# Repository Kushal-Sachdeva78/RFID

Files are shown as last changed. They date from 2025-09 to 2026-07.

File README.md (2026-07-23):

# RFID Entry-Exit System for Vasant Valley School

A prototype of an RFID-based attendance, entry-exit, and laptop-borrowing system
built around the school's existing ID cards: ESP32 firmware with an RC522 reader
and TFT status display, a custom KiCad PCB, a FastAPI backend with a test suite,
and a web dashboard with optional Firebase mirroring.






## Motivation

At Vasant Valley School, attendance is marked manually by class teachers,
latecomers wait in a morning "late line" for manual strike marking, student
exits run on paper sign-out sheets, and borrowing a laptop needs a paper chit
signed across several flights of stairs. This project prototypes a replacement:
students and staff tap their existing ID cards, and the system records who
arrived, when, whether they were late, which way they are authorised to travel
home, and who is holding which laptop.

## What is in this repo

| Component | Path | What it does |
| --- | --- | --- |
| ESP32 firmware | `Main.ino` | Reads RC522 taps, keeps a real clock over NTP (with a simulated fallback), renders a status card, weekly grid, and entry/exit banner on the ILI9341 TFT, and posts each scan to the backend over Wi-Fi with retry and an offline buffer. Pin assignments match the fabricated board. |
| Backend service | `rfid_system/backend` | A FastAPI REST API covering health, roster, attendance events (entry/exit direction and second-resolution lateness), an office manual fallback, three-strike teacher notification, and laptop borrowing. Pydantic v2, timezone-aware, a swappable storage layer, role-scoped API keys, and a pytest suite. |
| Web dashboard | `rfid_system/frontend` | A static dashboard showing the roster, attendance events with direction, a gate exit-authorization banner, manual entry, and a laptop borrowing panel. Optional Firebase mirroring of manual scans. |
| PCB design | `RFID KICAD/` | Full KiCad schematic and board layout integrating the ESP32 DevKit V1, RFID reader, display, buzzer, power switch, and battery holder, with exported Gerbers in `RFID KICAD/RFID_PCB/`. |

## Features

- Attendance to the second against a real clock, with the 08:05 cutoff and bus
  riders exempt from lateness. A repeat tap does not double-mark attendance.
- Entry and exit logging on a single gate reader (a per-day toggle), with the
  guard-facing display showing whether a departing student may walk, go by car,
  or take the bus.
- An office manual fallback for a forgotten or lost card, flagged manual and
  attributed to the staff member.
- Three late days in a learning cycle notify the class teacher through a
  pluggable notifier (a file/stdout default, or SMTP from environment
  variables). No credentials are committed.
- Laptop borrowing with a full state machine: a student requests, a teacher
  approves or denies, a tech-lab helper issues a numbered unit and records the
  return, and the dashboard shows outstanding loans and how long each is held.

## Hardware

| Component | Purpose |
| --- | --- |
| ESP32 DevKit V1 | Wi-Fi microcontroller running the firmware |
| RC522 RFID module (SPI) | Scans ID cards |
| ILI9341 320x240 TFT | Shows the scan result, lateness, direction, and transport authorization |
| Buzzer | Audible scan feedback |
| Custom PCB | Integrates the components (KiCad sources and Gerbers in this repo) |

The firmware pin defines match the nets on the fabricated board (RC522 SS on
GPIO14 and RST on GPIO27; TFT CS on GPIO5, DC on GPIO21, RST on GPIO22; buzzer on
GPIO15; shared SPI on GPIO18/23/19). Verify with a continuity check before
flashing a unit.

## Getting started

To run the software on a laptop with no hardware, follow
[`rfid_system/GETTING_STARTED.md`](rfid_system/GETTING_STARTED.md): it covers the
backend and its tests, the dashboard, compiling the firmware with `arduino-cli`,
the laptop borrowing flow, and optional Firebase setup.

Continuous integration (`.github/workflows/ci.yml`) runs the backend tests and a
firmware compile for the ESP32 DevKit V1 on every push.

## Status

Implemented in this prototype: the firmware (real clock, Wi-Fi posting, offline
buffer, corrected pins); the backend (attendance with direction and lateness,
manual fallback, three-strike notification, laptop borrowing) with a pytest
suite; the dashboard; and the complete PCB design.

Not yet done: Firebase Auth so the optional Firestore mirror can be enabled,
on-device roster caching so the gate can identify all cards while offline, and
real per-user authentication in place of the prototype role keys.

## Developed by

**Kushal Sachdeva**, Vasant Valley School

More of my work: [github.com/Kushal-Sachdeva78](https://github.com/Kushal-Sachdeva78),
including [autonomous RoboCup soccer robots](https://github.com/Kushal-Sachdeva78/VVS-Ballers-RoboCup)
and [EnerJee](https://github.com/Kushal-Sachdeva78/EnerJee), a renewable energy
planning platform.

## License

This project is licensed under the MIT License. See [LICENSE](LICENSE) for details.

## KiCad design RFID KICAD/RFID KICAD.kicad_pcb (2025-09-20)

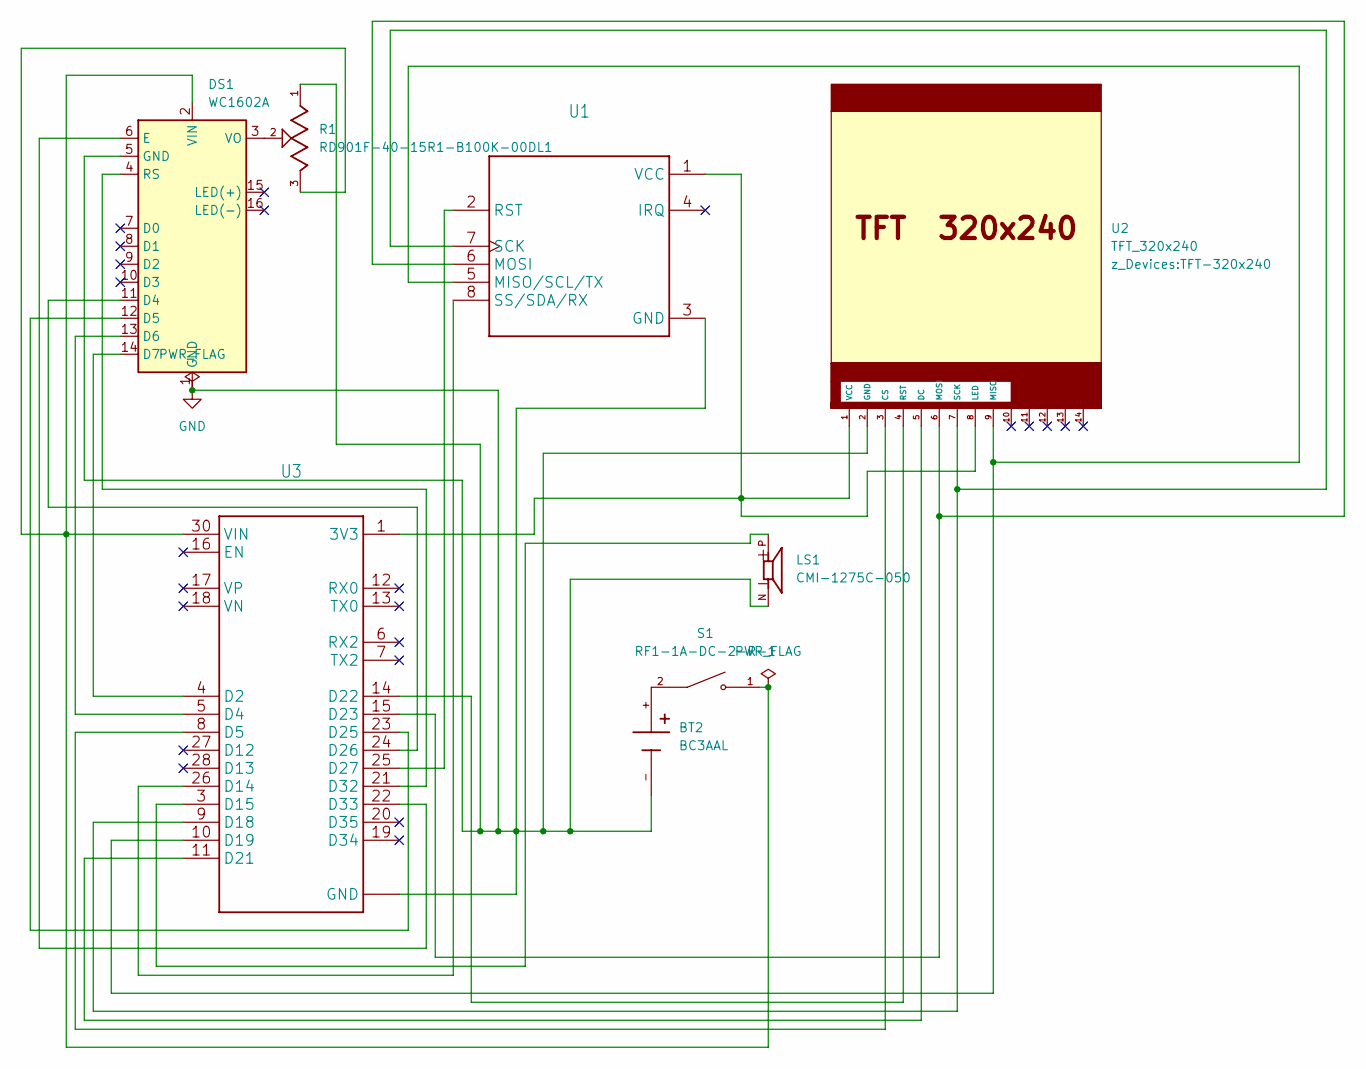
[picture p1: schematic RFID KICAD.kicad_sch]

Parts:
BT2: BC3AAL; BAT_BC3AAL; PARTREV J
DS1: WC1602A
LS1: CMI-1275C-050; CUI_CMI-1275C-050
R1: RD901F-40-15R1-B100K-00DL1; POT_RD901F-40-15R1-B100K-00DL1; PARTREV 10/5/23
S1: RF1-1A-DC-2-R-1; SW_RF1-1A-DC-2-R-1; PARTREV B
U1: MODULE_CEG006900
U2: TFT_320x240; TFT-320x240
U3: MODULE_ESP32_DEVKIT_V1

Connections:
GND: BT2.-, DS1.1 (GND), DS1.5 (GND), LS1.N, R1.1, U1.3 (GND), U2.2 (GND), U3.2 (GND), U3.29 (GND)
unnamed: BT2.+, S1.2
unnamed: DS1.11 (D4), U3.24 (D26)
unnamed: DS1.12 (D5), U3.23 (D25)
unnamed: DS1.13 (D6), U3.5 (D4)
unnamed: DS1.14 (D7), U3.4 (D2)
unnamed: DS1.6 (E), U3.22 (D33)
unnamed: DS1.4 (RS), U3.21 (D32)
unnamed: DS1.2 (VIN), R1.3, S1.1, U3.30 (VIN)
unnamed: DS1.3 (VO), R1.2
unnamed: U1.5 (MISO/SCL/TX), U2.9 (MISO), U3.10 (D19)
unnamed: U1.6 (MOSI), U2.6 (MOSI), U3.15 (D23)
unnamed: U1.2 (RST), U3.25 (D27)
unnamed: U1.7 (SCK), U2.7 (SCK), U3.9 (D18)
unnamed: U1.8 (SS/SDA/RX), U3.26 (D14)
unnamed: U1.1 (VCC), U2.1 (VCC), U2.8 (LED), U3.1 (3V3)
unnamed: U2.3 (CS), U3.8 (D5)
unnamed: U2.5 (DC), U3.11 (D21)
unnamed: U2.4 (RST), U3.14 (D22)
unnamed: LS1.P, U3.3 (D15)

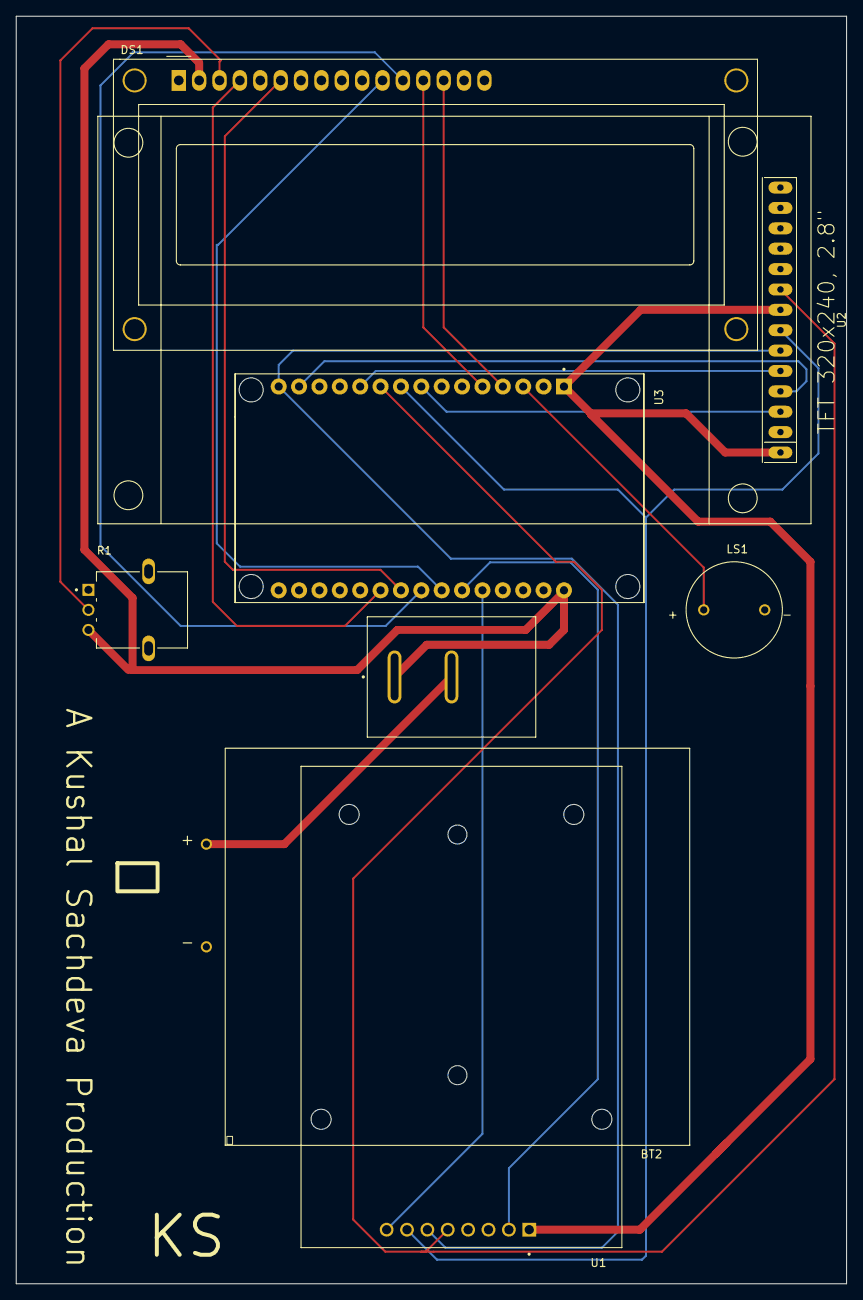
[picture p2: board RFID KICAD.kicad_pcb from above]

Board: 2 copper layers, 103.5 x 158.0 mm, 8 parts (0 on the bottom side), 20 nets.

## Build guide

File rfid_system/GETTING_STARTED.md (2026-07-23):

# Getting Started

Run the RFID system on a laptop with no hardware, then optionally compile the
firmware and wire up Firebase. Every step below runs with no credentials.

---

## 1. Backend

```bash
cd rfid_system/backend
python -m venv .venv
# macOS / Linux:
source .venv/bin/activate
# Windows (PowerShell):
.venv\Scripts\Activate.ps1

pip install -r requirements.txt -r requirements-dev.txt
uvicorn main:app --reload
```

The API listens on `http://127.0.0.1:8000`. Check it with:

```bash
curl http://127.0.0.1:8000/api/health
```

Run the tests:

```bash
pytest -q
```

### Configuration (all optional, via environment variables)

| Variable | Default | Purpose |
| --- | --- | --- |
| `RFID_TZ_OFFSET_MINUTES` | `330` | Local timezone offset. Default is India Standard Time (UTC+5:30, no daylight saving). |
| `RFID_LATE_HOUR` / `RFID_LATE_MINUTE` | `8` / `5` | Lateness cutoff (08:05). |
| `RFID_LEARNING_CYCLES` | one cycle, 08 Jul to 15 Oct 2026 | JSON array of `{name, start, end}` date ranges for strike tracking. |
| `RFID_STRIKE_THRESHOLD` | `3` | Late days in a cycle before the class teacher is notified. |
| `RFID_MAX_CONCURRENT_LOANS` | `1` | Active laptop loans a student may hold at once. |
| `RFID_SCAN_DEBOUNCE_SECONDS` | `60` | A repeat tap inside this window is a duplicate, not an exit. |
| `RFID_NOTIFIER` | `log` | Notifier backend: `log` (file plus stdout), `smtp`, or `none`. |
| `RFID_API_KEYS` | unset | JSON object of `{"key": "role"}` enabling role checks (see below). |

### Roles (prototype-grade)

By default there is no authentication, so the repo runs with no credentials.
When `RFID_API_KEYS` is set, privileged endpoints require an `X-API-Key` header
mapped to a role. This is a single shared key per role, not per-user login, and
is documented as a prototype, not production security. Example:

```bash
export RFID_API_KEYS='{"office-key":"office","teacher-key":"teacher","helper-key":"helper","admin-key":"admin"}'
```

Role requirements: manual attendance entry and roster writes need `office`,
`teacher`, or `admin`; laptop register or repair needs `helper` or `admin`; loan
approve or deny needs `teacher`; issue or return needs `helper`. The `admin` role
is allowed everywhere. Device scans and student borrow requests are open.

### Notifications (three-strike rule)

Three late days within a learning cycle notify the student's class teacher. The
class teacher is looked up in `data/class_teachers.json` by class section. The
default notifier writes to `data/notifications.log` and stdout, so no email
credentials are needed. To send email instead, set `RFID_NOTIFIER=smtp` and the
`SMTP_HOST`, `SMTP_PORT`, `SMTP_USER`, `SMTP_PASSWORD`, and `SMTP_FROM` variables.
No credentials are ever committed.

---

## 2. Dashboard

```bash
cd rfid_system/frontend
python -m http.server 5173
```

Browse to `http://localhost:5173`, enter the backend URL (`http://127.0.0.1:8000`)
in the Backend Connection card, and click Connect. The dashboard shows the roster,
attendance events with entry/exit direction, a gate preview with the exit
authorization banner, the manual entry form, and the laptop borrowing panel. If
the backend is stopped, manual scans are buffered locally.

---

## 3. Firmware (compile only)

The firmware target is the ESP32 DevKit V1. There is no hardware step here: a
clean compile is the gate.

```bash
arduino-cli core install esp32:esp32
arduino-cli lib install "MFRC522" "Adafruit GFX Library" "Adafruit ILI9341"
bash scripts/compile_firmware.sh
```

`scripts/compile_firmware.sh` stages `Main.ino` into `build/Main/` so the tracked
file is never moved. To run against hardware, copy `arduino_secrets.example.h` to
`arduino_secrets.h` (gitignored) and set your Wi-Fi and backend URL. With no
secrets file, or an empty SSID, the firmware runs fully offline.

---

## 4. Laptop borrowing flow

You can drive the whole flow from the dashboard Laptop Borrowing panel, or with
curl (with `RFID_API_KEYS` unset, no keys are needed):

```bash
B=http://127.0.0.1:8000
curl -s -X POST $B/api/laptops -H "Content-Type: application/json" -d '{"asset_code":"LT-042"}'
LOAN=$(curl -s -X POST $B/api/loans/request -H "Content-Type: application/json" -d '{"student_uid":"04 11 22 33"}' | python -c "import sys,json;print(json.load(sys.stdin)['id'])")
curl -s -X POST $B/api/loans/$LOAN/approve
curl -s -X POST $B/api/loans/$LOAN/issue -H "Content-Type: application/json" -d '{"asset_code":"LT-042"}'
curl -s $B/api/loans/outstanding
curl -s -X POST $B/api/loans/$LOAN/return
```

---

## 5. Firebase (optional)

Firestore mirroring of manual scans is optional. Copy the example config and fill
in your project:

```bash
cp rfid_system/frontend/firebase.config.example.js rfid_system/frontend/firebase.config.js
```

`firebase.config.js` is gitignored. When it is absent, the dashboard runs normally
with mirroring disabled. A Firebase web apiKey is not a secret (it ships to every
browser); the real protection is the Firestore rules below.

### Firestore security rules

These restrict access to authenticated clients. Wiring up Firebase Auth in the
dashboard is out of scope for this prototype, so mirroring is off until that is
added.

```text
rules_version = '2';
service cloud.firestore {
  match /databases/{database}/documents {
    match /manual_scans/{document=**} {
      allow read, write: if request.auth != null;
    }
  }
}
```

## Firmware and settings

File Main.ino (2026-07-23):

#include <WiFi.h>
#include <HTTPClient.h>
#include <SPI.h>
#include <MFRC522.h>
#include <Adafruit_GFX.h>
#include <Adafruit_ILI9341.h>
#include <ctype.h>
#include <string.h>
#include <time.h>

// -----------------------------------------------------------------------------
// Network and backend configuration.
// Real Wi-Fi credentials and the backend URL live in arduino_secrets.h, which
// is gitignored. Copy arduino_secrets.example.h to arduino_secrets.h and fill it
// in. When the header is absent (for example in CI, which only compiles), these
// placeholders keep the sketch building. With an empty SSID the firmware runs
// fully offline: it still reads cards and renders, and buffers scans to send
// later once a backend URL and network are configured.
// -----------------------------------------------------------------------------
#if __has_include("arduino_secrets.h")
#include "arduino_secrets.h"
#endif
#ifndef WIFI_SSID
#define WIFI_SSID ""
#endif
#ifndef WIFI_PASSWORD
#define WIFI_PASSWORD ""
#endif
#ifndef BACKEND_BASE_URL
#define BACKEND_BASE_URL "http://192.168.1.100:8000"
#endif
#ifndef READER_LOCATION
#define READER_LOCATION "main_gate"
#endif

// -----------------------------------------------------------------------------
// Hardware pin assignments.
// These match the nets on the fabricated KiCad board (ESP32 DevKit V1). The
// earlier values (SS 10, RST 9, TFT_RST 8, BUZZER 6) were leftover from a
// different board: they point at GPIO 6 to 11, which are bonded to the internal
// SPI flash on the WROOM-32 and are not broken out on the DevKit header. The
// shared SPI bus (SCK 18, MOSI 23, MISO 19) is the VSPI default and is wired to
// both the RC522 and the TFT. Verify with a continuity check before flashing.
// -----------------------------------------------------------------------------
#define RFID_SS    14   // RC522 SS   -> ESP32 D14
#define RFID_RST   27   // RC522 RST  -> ESP32 D27
#define TFT_CS      5   // ILI9341 CS  -> ESP32 D5
#define TFT_DC     21   // ILI9341 DC  -> ESP32 D21
#define TFT_RST    22   // ILI9341 RST -> ESP32 D22
#define BUZZER     15   // Buzzer      -> ESP32 D15

// -----------------------------------------------------------------------------
// RFID reader + TFT display objects
// -----------------------------------------------------------------------------
MFRC522 rfid(RFID_SS, RFID_RST);
Adafruit_ILI9341 tft(TFT_CS, TFT_DC, TFT_RST);

// -----------------------------------------------------------------------------
// Timings and attendance thresholds
// -----------------------------------------------------------------------------
const uint16_t DISPLAY_MS   = 5000;   // how long to show a scan before idling
const uint8_t  LATE_HOUR    = 8;
const uint8_t  LATE_MIN     = 5;
const uint8_t  START_HOUR   = 7;      // simulated start-of-day clock (fallback only)
const uint8_t  START_MINUTE = 45;

// -----------------------------------------------------------------------------
// Real clock (NTP) and networking constants.
// India Standard Time is UTC+5:30 with no daylight saving, so a fixed offset is
// exact all year. If NTP never syncs, the firmware falls back to the simulated
// clock above so the demo still works with no network.
// -----------------------------------------------------------------------------
const long     GMT_OFFSET_SEC       = 19800;  // +5:30
const int      DST_OFFSET_SEC       = 0;
const char*    NTP_SERVER_1         = "pool.ntp.org";
const char*    NTP_SERVER_2         = "time.nist.gov";
const char*    TZ_SUFFIX            = "+05:30"; // for ISO 8601 timestamps

const uint32_t WIFI_CONNECT_TIMEOUT_MS = 8000;  // bounded wait at startup
const uint32_t NET_MAINT_INTERVAL_MS   = 15000; // reconnect / resync / flush cadence
const uint8_t  HTTP_RETRIES            = 2;
const uint16_t HTTP_RETRY_DELAY_MS     = 200;
const uint16_t HTTP_TIMEOUT_MS         = 4000;

const int      OFFLINE_BUFFER_SIZE     = 32;   // scans held while offline
const int      PENDING_PAYLOAD_MAX     = 384;  // bytes per buffered scan

// -----------------------------------------------------------------------------
// Attendance data structures
// -----------------------------------------------------------------------------
enum AttendanceStatus : uint8_t {
  STATUS_ABSENT = 0,
  STATUS_PRESENT,
  STATUS_LATE
};

struct Person {
  const char* uid;          // hexadecimal UID string (space separated)
  const char* name;
  const char* role;         // Teacher / Student etc.
  const char* className;    // Homeroom or department label
  const char* transport;    // Mode of transport
  uint16_t    photoColor;   // Solid colour used for the mock photo tile
  AttendanceStatus week[5]; // Monday..Friday status history
  int lastDayKey;           // tracks the simulated day when this card was last marked
};

// Sample roster only. These names, UIDs, and sections are synthetic. On a real
// deployment the device would identify cards against the backend roster; this
// small on-device set is a fallback so the demo runs with no network.
Person roster[] = {
  {"04 11 22 33", "Sample Student", "Student", "Grade 10 - A", "Walk", ILI9341_BLUE,    {STATUS_ABSENT, STATUS_ABSENT, STATUS_ABSENT, STATUS_ABSENT, STATUS_ABSENT}, -1},
  {"04 44 55 66", "Sample Teacher", "Teacher", "Mathematics",  "Bus",  ILI9341_MAGENTA, {STATUS_ABSENT, STATUS_ABSENT, STATUS_ABSENT, STATUS_ABSENT, STATUS_ABSENT}, -1},
  {"04 77 88 99", "Demo Staff",     "Teacher", "Science",      "Car",  ILI9341_ORANGE,  {STATUS_ABSENT, STATUS_ABSENT, STATUS_ABSENT, STATUS_ABSENT, STATUS_ABSENT}, -1},
  {"04 AA BB CC", "Office Sample",  "Office",  "Admin",        "Car",  ILI9341_CYAN,    {STATUS_ABSENT, STATUS_ABSENT, STATUS_ABSENT, STATUS_ABSENT, STATUS_ABSENT}, -1}
};
const int ROSTER_COUNT = sizeof(roster) / sizeof(roster[0]);

// -----------------------------------------------------------------------------
// Global state used for simulated clock + display transitions
// -----------------------------------------------------------------------------
uint32_t bootMillis = 0;
uint32_t lastScreenUpdate = 0;
bool showingScan = false;
int initialisedDayKey = -1;

// Networking / clock state.
bool wifiConfigured = false;   // true when a non-empty SSID is compiled in
bool timeSynced = false;       // true once NTP has given us a real time
uint32_t lastNetMaintenance = 0;

// Guard-facing result of the most recent live scan, taken from the backend
// response headers (no JSON parsing needed on the device).
String lastDirection = "";
String lastAuthorization = "";

// Offline buffer: scans that could not be posted are kept here and flushed
// (oldest first) once the backend is reachable again.
struct PendingEvent {
  char payload[PENDING_PAYLOAD_MAX];
};
PendingEvent offlineBuffer[OFFLINE_BUFFER_SIZE];
int offlineCount = 0;
bool offlineDropped = false;   // set if the buffer overflowed (oldest dropped)

// -----------------------------------------------------------------------------
// Utility helpers
// -----------------------------------------------------------------------------
String uidToString(const MFRC522::Uid& uid) {
  String s;
  for (byte i = 0; i < uid.size; i++) {
    if (uid.uidByte[i] < 0x10) s += "0";
    s += String(uid.uidByte[i], HEX);
    if (i != uid.size - 1) s += " ";
  }
  s.toUpperCase();
  return s;
}

void softClockNow(int& hour, int& minute, int& dayKey) {
  uint32_t elapsedMinutes = (millis() - bootMillis) / 60000UL;
  uint32_t startMinutes   = START_HOUR * 60UL + START_MINUTE;
  uint32_t totalMinutes   = startMinutes + elapsedMinutes;

  hour   = (totalMinutes / 60UL) % 24;
  minute = totalMinutes % 60UL;
  dayKey = totalMinutes / (24UL * 60UL);
}

uint8_t currentWeekday(int dayKey) {
  // With a real clock, derive the weekday from the date. Monday maps to 0 and
  // Friday to 4; weekend days are clamped into the Friday column so the fixed
  // five column weekly grid never indexes out of bounds.
  if (timeSynced) {
    struct tm t;
    if (getLocalTime(&t, 0)) {
      uint8_t wd = (uint8_t)((t.tm_wday + 6) % 7); // Sun=0..Sat=6 -> Mon=0..Sun=6
      return wd > 4 ? 4 : wd;
    }
  }
  return dayKey % 5; // Monday (0) .. Friday (4) in the simulated fallback
}

bool arrivedLate(int hour, int minute, const char* transport) {
  if (transport != nullptr) {
    char first = transport[0];
    if (first == 'B' || first == 'b') {
      return false; // bus riders are exempt from lateness cutoffs
    }
  }
  if (hour > LATE_HOUR) return true;
  if (hour == LATE_HOUR && minute > LATE_MIN) return true;
  return false;
}

void toneOk() {
  digitalWrite(BUZZER, HIGH);
  delay(60);
  digitalWrite(BUZZER, LOW);
}

void toneError() {
  for (uint8_t i = 0; i < 2; ++i) {
    digitalWrite(BUZZER, HIGH);
    delay(40);
    digitalWrite(BUZZER, LOW);
    delay(40);
  }
}

String initialsOf(const char* name) {
  String initials;
  bool takeNext = true;
  for (const char* p = name; *p; ++p) {
    if (takeNext && isalpha(*p)) {
      initials += (char)toupper(*p);
      takeNext = false;
    }
    if (*p == ' ') {
      takeNext = true;
    }
    if (initials.length() == 2) break;
  }
  if (initials.length() == 0) {
    initials = "??";
  } else if (initials.length() == 1) {
    initials += initials[0];
  }
  return initials;
}

void ensureDayPrepared(int dayKey) {
  if (dayKey == initialisedDayKey) {
    return;
  }
  initialisedDayKey = dayKey;
  uint8_t weekday = currentWeekday(dayKey);
  for (int i = 0; i < ROSTER_COUNT; ++i) {
    if (roster[i].lastDayKey != dayKey) {
      roster[i].week[weekday] = STATUS_ABSENT;
    }
  }
}

// -----------------------------------------------------------------------------
// Drawing helpers
// -----------------------------------------------------------------------------
void drawIdleScreen() {
  tft.fillScreen(ILI9341_BLACK);
  tft.setTextColor(ILI9341_YELLOW);
  tft.setTextSize(3);
  tft.setCursor(30, 60);
  tft.println("TAP RFID");
  tft.setCursor(30, 110);
  tft.println("TO SIGN IN");
}

void drawClockOverlay(int hour, int minute) {
  tft.fillRect(180, 0, 140, 28, ILI9341_BLACK);
  tft.setTextColor(ILI9341_WHITE);
  tft.setTextSize(2);
  tft.setCursor(190, 6);
  if (hour < 10) tft.print('0');
  tft.print(hour);
  tft.print(':');
  if (minute < 10) tft.print('0');
  tft.print(minute);
}

void drawMockPhoto(uint16_t color, const String& initials) {
  const int x = 12;
  const int y = 16;
  const int w = 96;
  const int h = 96;

  tft.fillRoundRect(x, y, w, h, 12, color);
  tft.drawRoundRect(x, y, w, h, 12, ILI9341_WHITE);

  tft.setTextColor(ILI9341_WHITE);
  tft.setTextSize(4);
  int16_t x1, y1;
  uint16_t w1, h1;
  tft.getTextBounds(initials.c_str(), x, y, &x1, &y1, &w1, &h1);
  int textX = x + (w - (int)w1) / 2;
  int textY = y + (h + (int)h1) / 2 - 12;
  tft.setCursor(textX, textY);
  tft.print(initials);
}

void drawStatusIcon(int x, int y, int size, AttendanceStatus status) {
  tft.fillRect(x, y, size, size, ILI9341_BLACK);
  switch (status) {
    case STATUS_PRESENT:
      tft.drawRoundRect(x, y, size, size, 6, ILI9341_GREEN);
      tft.drawLine(x + 6, y + size / 2, x + size / 3, y + size - 6, ILI9341_GREEN);
      tft.drawLine(x + size / 3, y + size - 6, x + size - 6, y + 6, ILI9341_GREEN);
      break;
    case STATUS_LATE:
      tft.drawRoundRect(x, y, size, size, 6, ILI9341_YELLOW);
      tft.drawLine(x + 6, y + size / 2, x + size - 6, y + size / 2, ILI9341_YELLOW);
      break;
    case STATUS_ABSENT:
    default:
      tft.drawRoundRect(x, y, size, size, 6, ILI9341_RED);
      tft.drawLine(x + 6, y + 6, x + size - 6, y + size - 6, ILI9341_RED);
      tft.drawLine(x + size - 6, y + 6, x + 6, y + size - 6, ILI9341_RED);
      break;
  }
}

void drawWeeklyTable(const Person& person) {
  const char* DAY_NAMES[5] = {"Mon", "Tue", "Wed", "Thu", "Fri"};
  const int startX = 12;
  const int startY = 140;
  const int cellSize = 44;

  tft.setTextSize(2);
  for (int i = 0; i < 5; ++i) {
    int x = startX + i * (cellSize + 12);
    tft.setTextColor(ILI9341_WHITE);
    tft.setCursor(x, startY - 24);
    tft.print(DAY_NAMES[i]);
    drawStatusIcon(x, startY, cellSize, person.week[i]);
  }
}

void drawPersonCard(const Person& person, bool duplicate, bool late, int hour, int minute) {
  tft.fillScreen(ILI9341_BLACK);

  drawMockPhoto(person.photoColor, initialsOf(person.name));

  tft.setTextColor(ILI9341_CYAN);
  tft.setTextSize(2);
  tft.setCursor(120, 24);
  tft.print("Name: ");
  tft.setTextColor(ILI9341_WHITE);
  tft.println(person.name);

  tft.setTextColor(ILI9341_CYAN);
  tft.setCursor(120, 52);
  tft.print("Role: ");
  tft.setTextColor(ILI9341_WHITE);
  tft.println(person.role);
  if (person.className && strlen(person.className) > 0) {
    tft.setCursor(120, 72);
    tft.setTextColor(ILI9341_WHITE);
    tft.println(person.className);
  }

  tft.setTextColor(ILI9341_CYAN);
  tft.setCursor(120, 100);
  tft.print("Mode: ");
  tft.setTextColor(ILI9341_WHITE);
  tft.println(person.transport);

  tft.setCursor(120, 128);
  tft.setTextColor(ILI9341_CYAN);
  tft.print("Time: ");
  tft.setTextColor(ILI9341_WHITE);
  if (hour < 10) tft.print('0');
  tft.print(hour);
  tft.print(':');
  if (minute < 10) tft.print('0');
  tft.print(minute);

  tft.setCursor(120, 156);
  if (duplicate) {
    tft.setTextColor(ILI9341_YELLOW);
    tft.println("Already checked in");
  } else if (late) {
    tft.setTextColor(ILI9341_ORANGE);
    tft.println("Status: LATE");
  } else {
    tft.setTextColor(ILI9341_GREEN);
    tft.println("Status: ON TIME");
  }

  drawWeeklyTable(person);
  drawClockOverlay(hour, minute);
}

void drawUnknownCard(const String& uid) {
  tft.fillScreen(ILI9341_BLACK);
  tft.setTextColor(ILI9341_RED);
  tft.setTextSize(3);
  tft.setCursor(20, 80);
  tft.println("UNKNOWN CARD");
  tft.setTextSize(2);
  tft.setCursor(20, 130);
  tft.print(uid);
}

// -----------------------------------------------------------------------------
// Core attendance handling
// -----------------------------------------------------------------------------
void markAttendance(Person& person, bool late, int dayKey) {
  uint8_t weekday = currentWeekday(dayKey);
  person.week[weekday] = late ? STATUS_LATE : STATUS_PRESENT;
  person.lastDayKey = dayKey;
}

// -----------------------------------------------------------------------------
// Real clock (NTP with simulated fallback)
// -----------------------------------------------------------------------------
void clockNow(int& hour, int& minute, int& second, int& dayKey) {
  if (timeSynced) {
    struct tm t;
    if (getLocalTime(&t, 0)) {
      hour = t.tm_hour;
      minute = t.tm_min;
      second = t.tm_sec;
      long localEpoch = (long)time(nullptr) + GMT_OFFSET_SEC;
      dayKey = (int)(localEpoch / 86400L);
      return;
    }
  }
  // Fallback: simulated clock (minute resolution); seconds from millis.
  softClockNow(hour, minute, dayKey);
  second = (int)((millis() / 1000UL) % 60UL);
}

String isoNow() {
  if (timeSynced) {
    struct tm t;
    if (getLocalTime(&t, 0)) {
      char buf[24];
      strftime(buf, sizeof(buf), "%Y-%m-%dT%H:%M:%S", &t);
      return String(buf) + TZ_SUFFIX;
    }
  }
  return String(""); // unknown: let the backend stamp arrival time
}

// -----------------------------------------------------------------------------
// Wi-Fi and NTP
// -----------------------------------------------------------------------------
void syncTime() {
  configTime(GMT_OFFSET_SEC, DST_OFFSET_SEC, NTP_SERVER_1, NTP_SERVER_2);
  struct tm t;
  if (getLocalTime(&t, 3000)) { // short bounded wait so the loop is not stalled
    timeSynced = true;
  }
}

void connectWifiBlocking() {
  if (!wifiConfigured) return;
  WiFi.mode(WIFI_STA);
  WiFi.begin(WIFI_SSID, WIFI_PASSWORD);
  uint32_t start = millis();
  while (WiFi.status() != WL_CONNECTED && (millis() - start) < WIFI_CONNECT_TIMEOUT_MS) {
    delay(150);
  }
}

// -----------------------------------------------------------------------------
// Backend posting with retry and an offline buffer
// -----------------------------------------------------------------------------
bool postEvent(const String& payload) {
  if (WiFi.status() != WL_CONNECTED) return false;
  static const char* headerKeys[] = {"X-Direction", "X-Transport-Authorization"};
  bool ok = false;
  HTTPClient http;
  http.setTimeout(HTTP_TIMEOUT_MS);
  String url = String(BACKEND_BASE_URL) + "/api/logs";
  for (uint8_t attempt = 0; attempt < HTTP_RETRIES && !ok; ++attempt) {
    if (!http.begin(url)) break;
    http.addHeader("Content-Type", "application/json");
    http.collectHeaders(headerKeys, 2);
    int code = http.POST(payload);
    if (code >= 200 && code < 300) {
      lastDirection = http.header("X-Direction");
      lastAuthorization = http.header("X-Transport-Authorization");
      ok = true;
    }
    http.end();
    if (!ok) {
      delay(HTTP_RETRY_DELAY_MS);
    }
  }
  return ok;
}

void bufferEvent(const String& payload) {
  if (offlineCount >= OFFLINE_BUFFER_SIZE) {
    // Buffer full: drop the oldest to make room for the newest scan.
    for (int i = 1; i < OFFLINE_BUFFER_SIZE; ++i) {
      offlineBuffer[i - 1] = offlineBuffer[i];
    }
    offlineCount = OFFLINE_BUFFER_SIZE - 1;
    offlineDropped = true;
  }
  strncpy(offlineBuffer[offlineCount].payload, payload.c_str(), PENDING_PAYLOAD_MAX - 1);
  offlineBuffer[offlineCount].payload[PENDING_PAYLOAD_MAX - 1] = '\0';
  offlineCount++;
}

void flushOfflineBuffer() {
  while (offlineCount > 0 && WiFi.status() == WL_CONNECTED) {
    if (!postEvent(String(offlineBuffer[0].payload))) {
      break; // still unreachable; keep the rest for the next attempt
    }
    for (int i = 1; i < offlineCount; ++i) {
      offlineBuffer[i - 1] = offlineBuffer[i];
    }
    offlineCount--;
  }
}

// Draw the entry/exit banner at the bottom of the card. On exit it also shows
// how the student is authorised to travel home (walk, car, or bus).
void drawGateBanner(const String& direction, const String& authorization) {
  const int y = 210;
  tft.fillRect(0, y, 320, 30, ILI9341_BLACK);
  tft.setCursor(8, y + 2);
  tft.setTextSize(2);
  if (direction == "exit") {
    tft.setTextColor(ILI9341_CYAN);
    tft.print("EXIT");
  } else if (direction == "entry") {
    tft.setTextColor(ILI9341_GREEN);
    tft.print("ENTRY");
  } else {
    return;
  }
  if (authorization.length() > 0) {
    tft.setTextSize(1);
    tft.setTextColor(ILI9341_WHITE);
    tft.setCursor(96, y + 8);
    tft.print(authorization);
  }
}

String jsonEscape(const char* s) {
  String out;
  if (s == nullptr) return out;
  for (const char* p = s; *p; ++p) {
    char c = *p;
    if (c == '"' || c == '\\') {
      out += '\\';
      out += c;
    } else if (c == '\n' || c == '\r' || c == '\t') {
      out += ' ';
    } else {
      out += c;
    }
  }
  return out;
}

String buildScanPayload(const String& uid, const char* status, const Person* person,
                        bool late, int lateMinutes) {
  String p = "{";
  p += "\"uid\":\"" + jsonEscape(uid.c_str()) + "\",";
  p += "\"status\":\"" + String(status) + "\",";
  p += "\"reader_location\":\"" + jsonEscape(READER_LOCATION) + "\"";
  String ts = isoNow();
  if (ts.length() > 0) {
    p += ",\"timestamp\":\"" + ts + "\"";
  }
  if (person != nullptr) {
    p += ",\"person\":{";
    p += "\"uid\":\"" + jsonEscape(uid.c_str()) + "\",";
    p += "\"name\":\"" + jsonEscape(person->name) + "\",";
    p += "\"role\":\"" + jsonEscape(person->role) + "\",";
    p += "\"transport\":\"" + jsonEscape(person->transport) + "\"";
    if (person->className != nullptr && strlen(person->className) > 0) {
      p += ",\"class_name\":\"" + jsonEscape(person->className) + "\"";
    }
    p += "}";
  }
  p += ",\"lateness\":{\"late\":";
  p += late ? "true" : "false";
  p += ",\"minutes\":" + String(lateMinutes) + "}";
  p += "}";
  return p;
}

void reportScan(const String& uid, const char* status, const Person* person,
                bool late, int lateMinutes) {
  if (!wifiConfigured) return; // no network configured: pure offline demo
  String payload = buildScanPayload(uid, status, person, late, lateMinutes);
  lastDirection = "";
  lastAuthorization = "";
  if (postEvent(payload)) {
    if (lastDirection.length() > 0) {
      drawGateBanner(lastDirection, lastAuthorization);
    }
  } else {
    bufferEvent(payload); // offline: keep it and flush when the backend returns
  }
}
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
void loop() {
  int hour, minute, second, dayKey;
  clockNow(hour, minute, second, dayKey);
  ensureDayPrepared(dayKey);
  maintainNetwork();

  if (showingScan && (millis() - lastScreenUpdate) > DISPLAY_MS) {
    showingScan = false;
    drawIdleScreen();
  }

  drawClockOverlay(hour, minute);

  if (!rfid.PICC_IsNewCardPresent() || !rfid.PICC_ReadCardSerial()) {
    return;
  }

  String uid = uidToString(rfid.uid);
  rfid.PICC_HaltA();

  int match = -1;
  for (int i = 0; i < ROSTER_COUNT; ++i) {
    if (uid == roster[i].uid) {
      match = i;
      break;
    }
  }

  if (match < 0) {
    toneError();
    drawUnknownCard(uid);
    lastScreenUpdate = millis();
    showingScan = true;
    reportScan(uid, "rejected", nullptr, false, 0);
    return;
  }

  Person& person = roster[match];
  bool alreadyToday = (person.lastDayKey == dayKey);
  bool late = arrivedLate(hour, minute, person.transport);

  if (!alreadyToday) {
    markAttendance(person, late, dayKey);
  }

  toneOk();
  drawPersonCard(person, alreadyToday, late, hour, minute);
  lastScreenUpdate = millis();
  showingScan = true;

  // Report to the backend after rendering so the display stays responsive.
  int lateMinutes = 0;
  if (late) {
    int nowMinutes = hour * 60 + minute;
    int cutoffMinutes = LATE_HOUR * 60 + LATE_MIN;
    lateMinutes = nowMinutes > cutoffMinutes ? (nowMinutes - cutoffMinutes) : 0;
  }
  const char* status = alreadyToday ? "duplicate" : (late ? "late" : "accepted");
  reportScan(uid, status, &person, late, lateMinutes);
}

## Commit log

2025-11-08 Add full-stack support for ESP32 RFID system
2025-11-08 Add SPI screen preview and roster metadata to dashboard
2025-11-09 Create Teensy-focused TFT attendance firmware
2026-07-23 feat(firmware): real NTP clock, backend posting with offline buffer, board pins
    Phase 2: firmware networking and real time, plus the approved pin-define fix.
    - Pin defines now match the fabricated KiCad board (approved in planning):
    RC522 SS->D14, RST->D27; ILI9341 CS->D5, DC->D21, RST->D22; buzzer->D15. The
    old values targeted GPIO 6 to 11, which are bonded to the WROOM-32 SPI flash
    and not broken out. This is schematic derived; continuity check a unit before
    flashing.
    - Real clock via NTP (configTime, IST UTC+5:30). If sync fails, the firmware
    falls back to the previous simulated millis clock so the demo still runs with
    no network. Weekday is taken from the real date when sync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
    [Main.ino]
2026-07-23 feat(laptops): laptop borrowing state machine with dashboard and end-to-end flow
    Phase 5, implementing the approved design.
    State machine: requested -> approved -> issued -> returned, with denied,
    expired (uncollected past the end-of-day deadline), and cancelled branches.
    Laptop assets: available <-> on_loan, plus under_repair and retired.
    Decisions from planning: return is a helper action; teachers approve remotely
    from the dashboard; a student holds at most one active loan (configurable via
    RFID_MAX_CONCURRENT_LOANS, default 1); an approved request that is not collected
    expires at the end of the day, computed lazily on read with a manual expire
    endpoint as well.
    Endpoints (privileged on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
2026-07-23 docs: rewrite README and guide, synthetic sample data, Firebase config pattern
    Phase 6 (documentation and hygiene), excluding the tracked-artifact removals,
    which wait on confirmation.
    - Rewrite README.md and GETTING_STARTED.md to match the system as it now stands:
    attendance with direction and lateness, the manual fallback, three-strike
    notification, laptop borrowing, roles, the config env vars, the arduino-cli
    compile, and the end-to-end borrow flow. No deployment or usage claims.
    - Replace the sample roster with obviously synthetic data (the firmware array in
    Main.ino and data/roster.json): fake names, synthetic UIDs, sections aligned to
    class_teachers.json, and no stock photos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
    [Main.ino]
2026-07-23 chore: stop tracking KiCad footprint cache and backup archives
    Remove fp-info-cache (about 4 MB) and the five RFID2-backups/*.zip editor backup
    archives from version control with git rm --cached (the local files are kept) and
    add them to .gitignore. These are regenerated artifacts, not source. RFID_PCB.zip
    and all KiCad design sources stay tracked. No history was rewritten.
2026-11-08 docs: add contributing guide and issue forms
    Adds CONTRIBUTING.md with test commands, ground rules and a response-time note, a bug form and an improvement form.
2026-11-08 docs: cut the changelog for v0.1.0
    Moves the unreleased entries under [0.1.0] - 2026-11-09 ahead of tagging the first release.

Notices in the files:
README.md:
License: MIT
